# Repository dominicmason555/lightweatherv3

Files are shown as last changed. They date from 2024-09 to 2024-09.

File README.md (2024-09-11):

# Light Weather V3

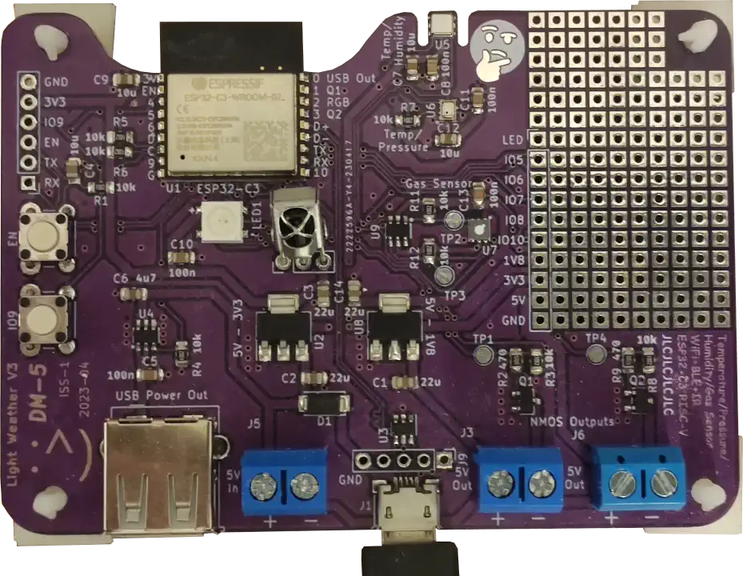
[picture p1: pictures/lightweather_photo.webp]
Photo of assembled project PCB


I made a temperature/pressure/humidity/gas sensor and general I/O interface for
my "smart flat".

[Full write-up](https://domson.dev/projects/lightweather.html) of versions 1
through 3 (this version) on my [personal website](https://domson.dev).

It features an ESP32-C3 controlling two NMOS outputs, one current-limited USB A
(power only) output, and an addressable RGB LED. It has pressure, temperature,
humidity, and gas sensors, and an IR receiver. These can be controlled using
MQTT over WiFi, or using an IR remote.

- [Schematic](./pictures/lightweather_schematic.pdf)
- [Firmware](./firmware/)

The hardware and firmware are open-source, the firmware (everything in
the [firmware](./firmware/) directory) is licensed under the
[GPL V3](./firmware/LICENSE).
The hardware (everything else) is licensed under the
[CERN Open Hardware Licence Version 2 - Strongly Reciprocal](./LICENSE).
The general gist is that if you feel like using or modifying anything here,
good luck, have fun, and publish what you make as open-source too.

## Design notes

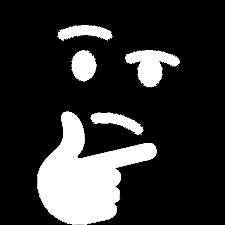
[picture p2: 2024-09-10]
Images/thinkmask.png

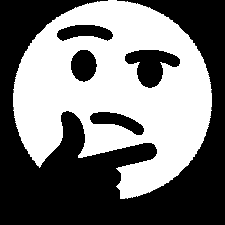
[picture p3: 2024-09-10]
Images/thinksilk.png

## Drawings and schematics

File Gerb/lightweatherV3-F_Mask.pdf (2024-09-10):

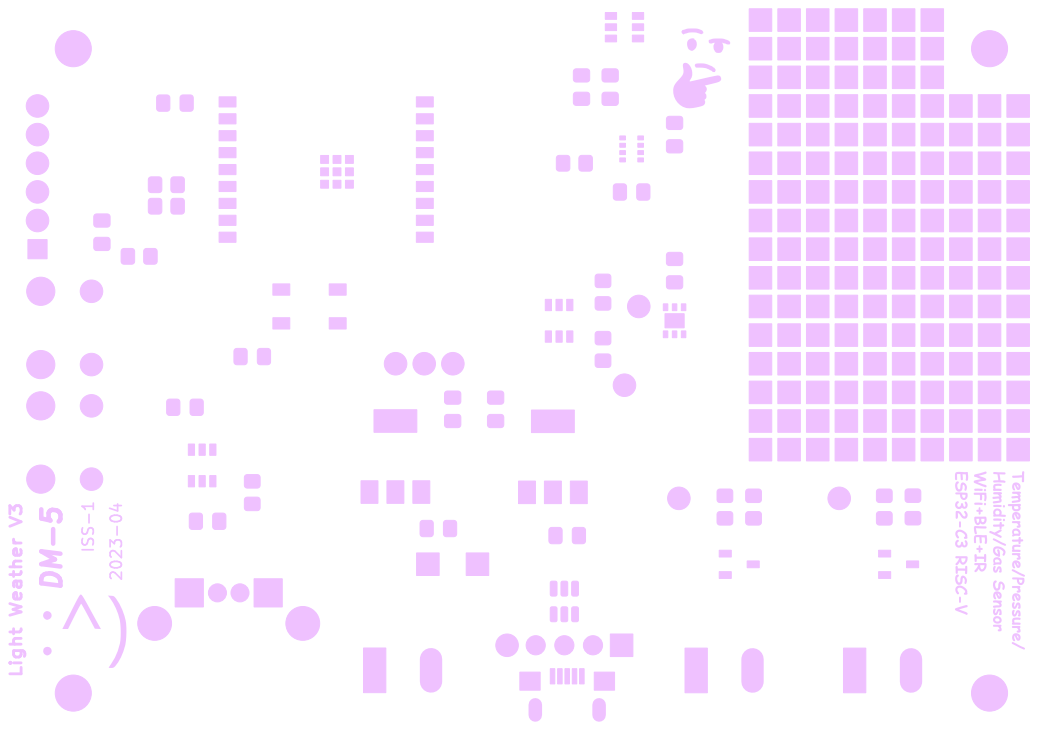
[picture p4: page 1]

ISS-1 2023-04 Humidity/Gas Temperature/Pressure/ Sensor ESP32-C3 WiFi+BLE+IRRISC-VDM-5 Light Weather V3

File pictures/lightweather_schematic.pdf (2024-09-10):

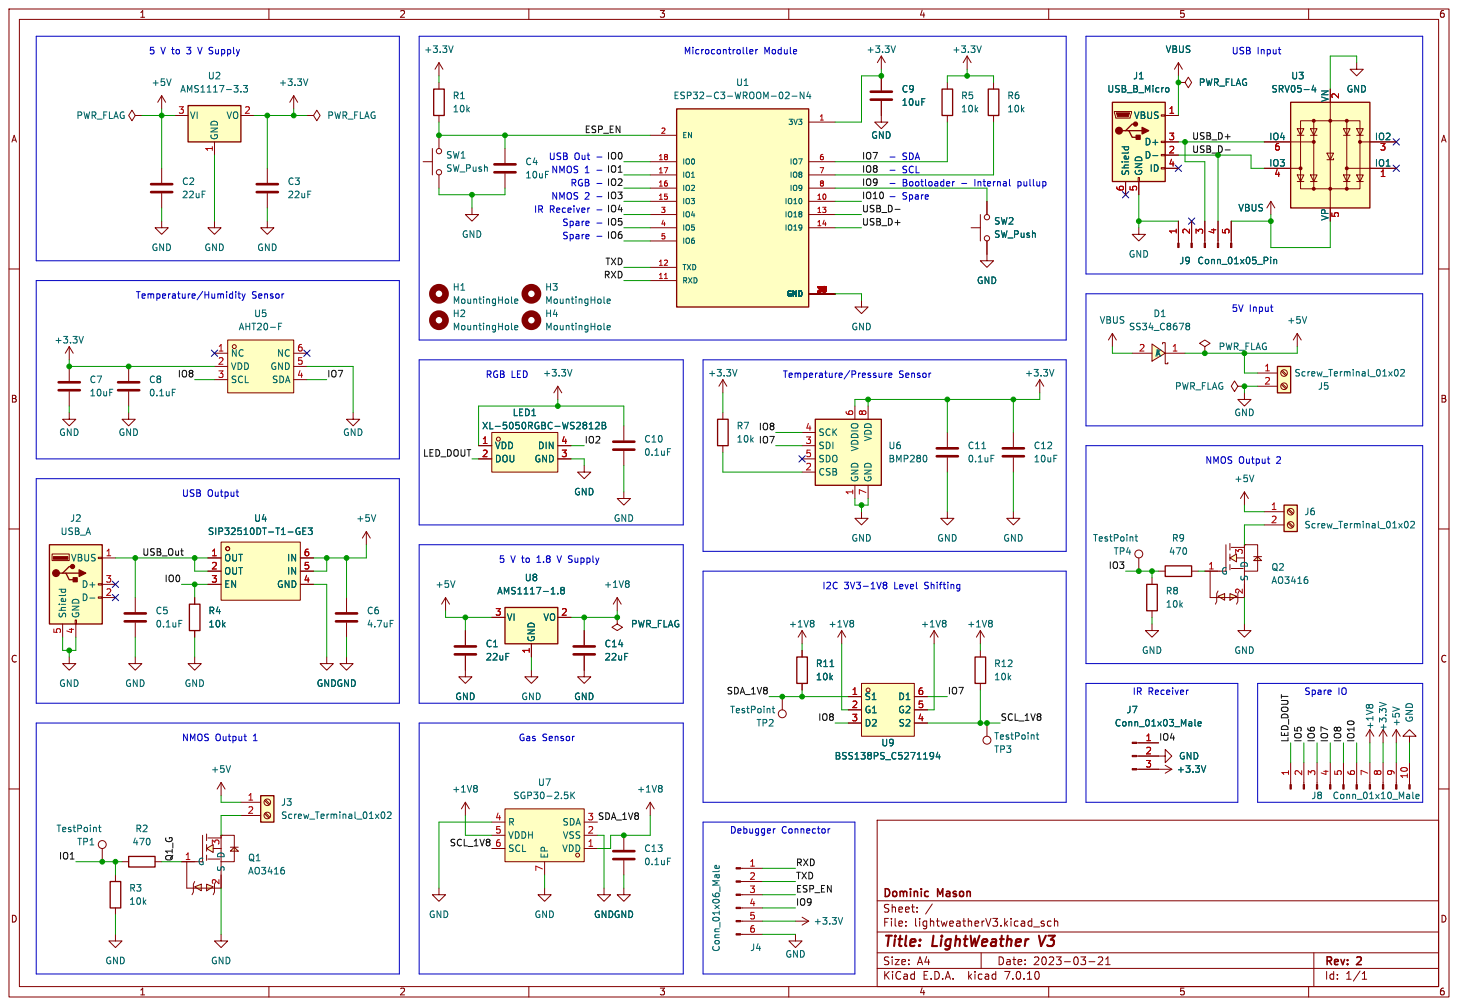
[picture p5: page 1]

1 CSB 2 SDI 3 SCK 4 SDO 5 VDDIO

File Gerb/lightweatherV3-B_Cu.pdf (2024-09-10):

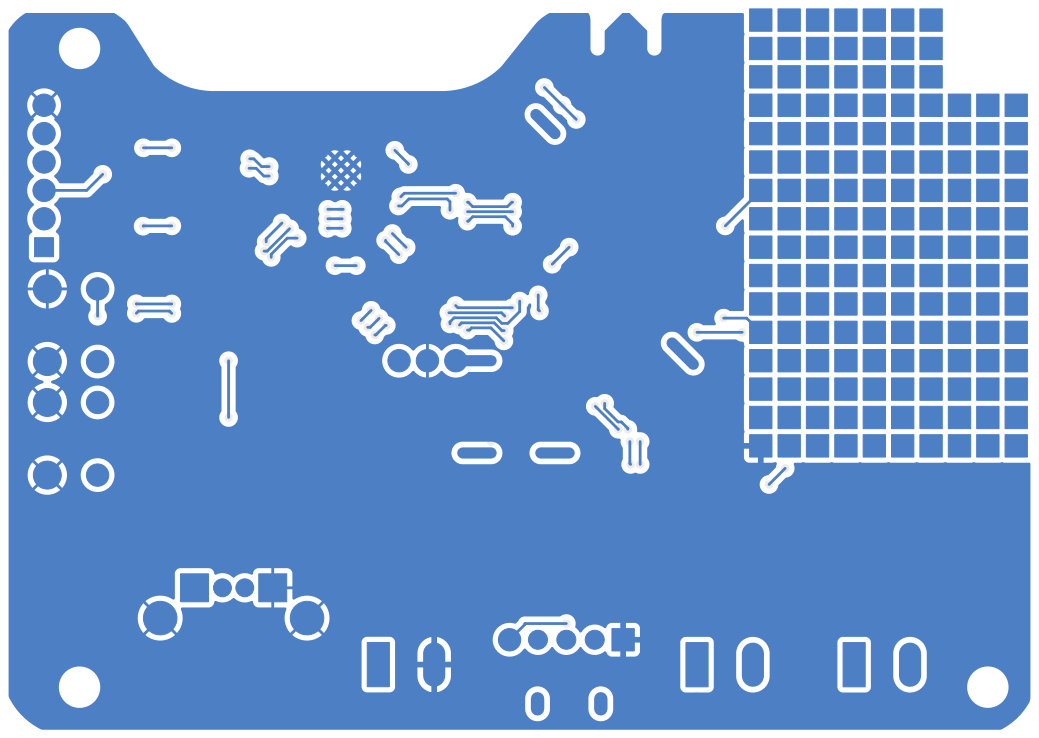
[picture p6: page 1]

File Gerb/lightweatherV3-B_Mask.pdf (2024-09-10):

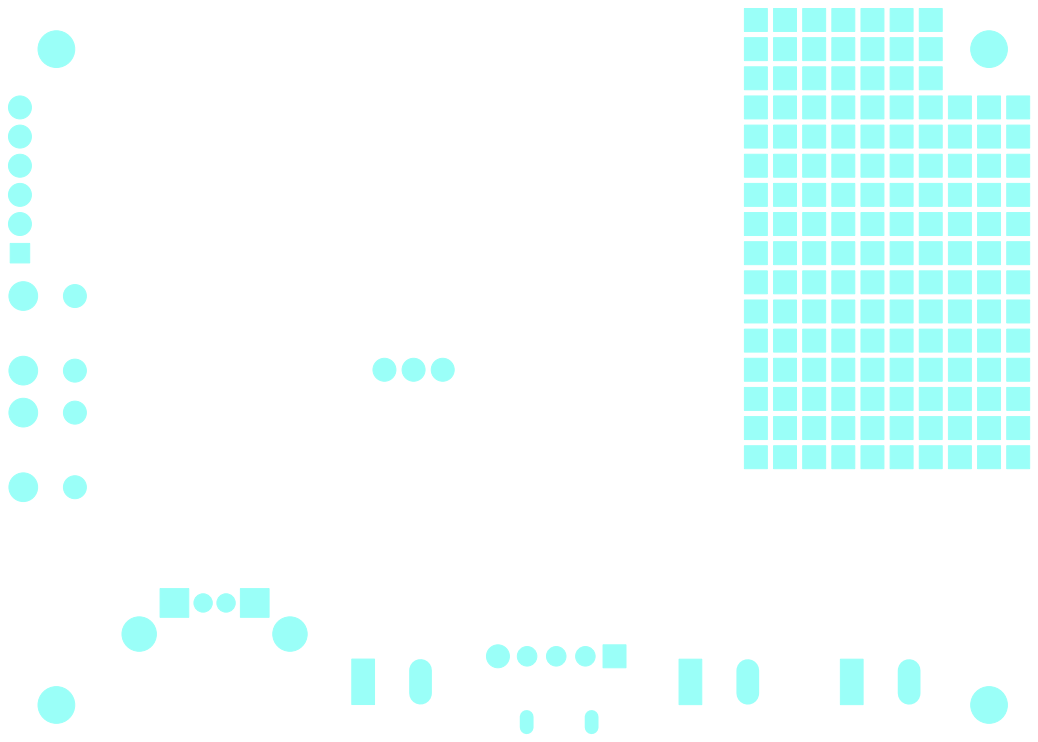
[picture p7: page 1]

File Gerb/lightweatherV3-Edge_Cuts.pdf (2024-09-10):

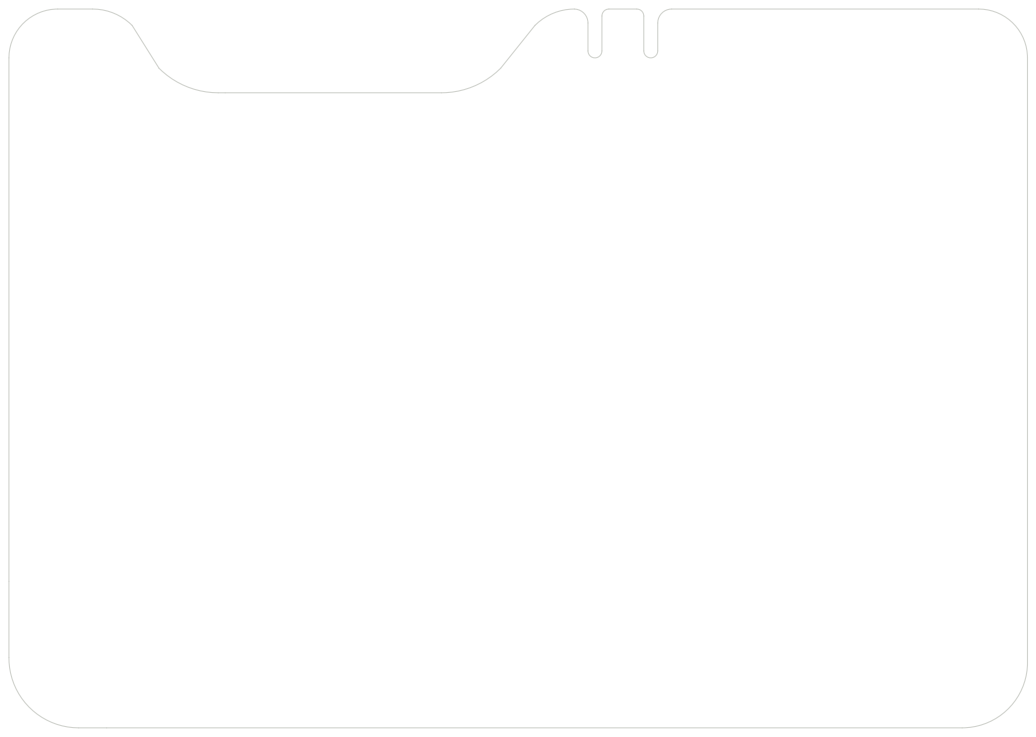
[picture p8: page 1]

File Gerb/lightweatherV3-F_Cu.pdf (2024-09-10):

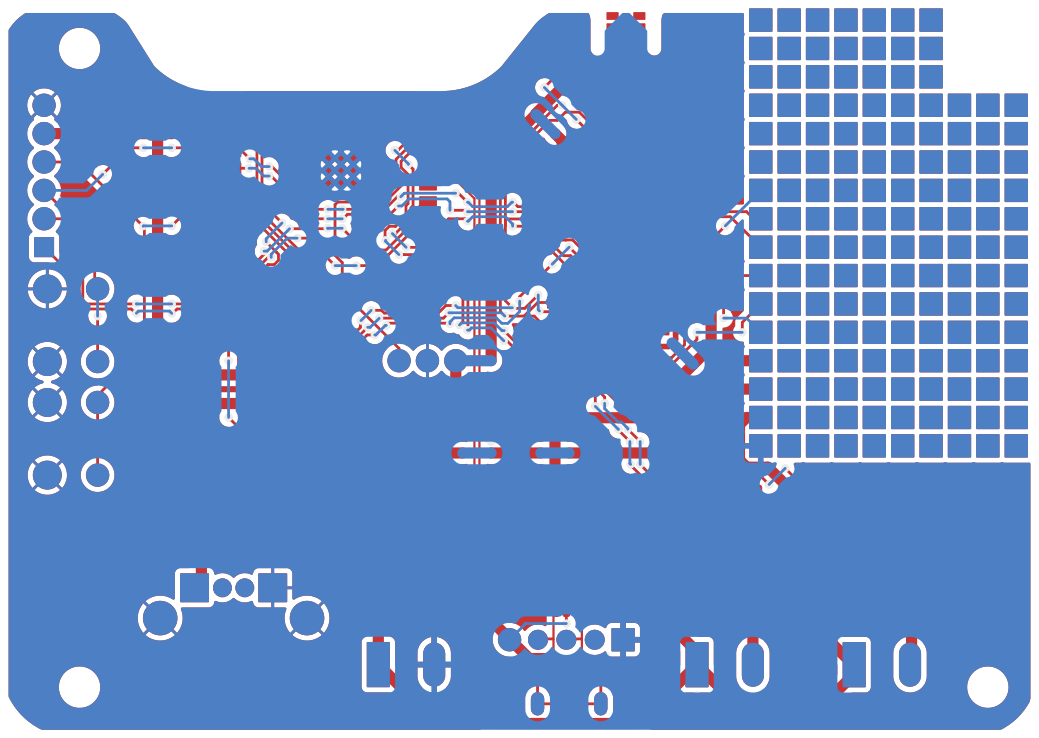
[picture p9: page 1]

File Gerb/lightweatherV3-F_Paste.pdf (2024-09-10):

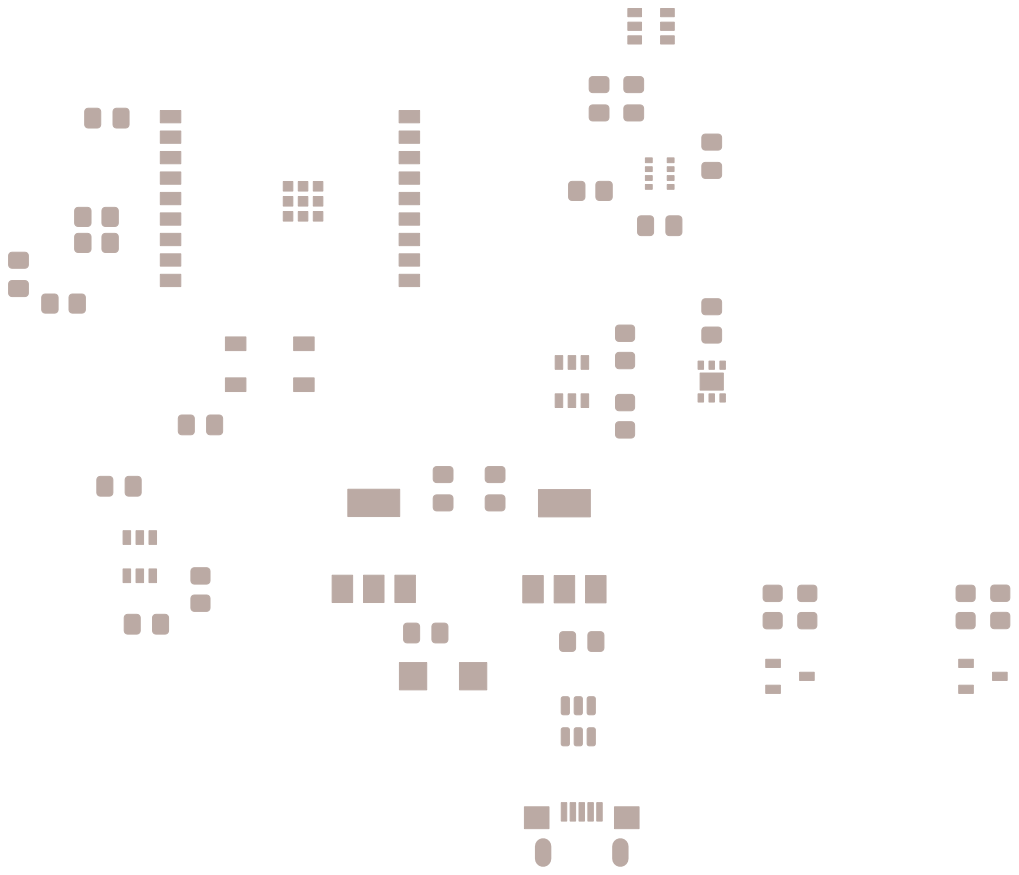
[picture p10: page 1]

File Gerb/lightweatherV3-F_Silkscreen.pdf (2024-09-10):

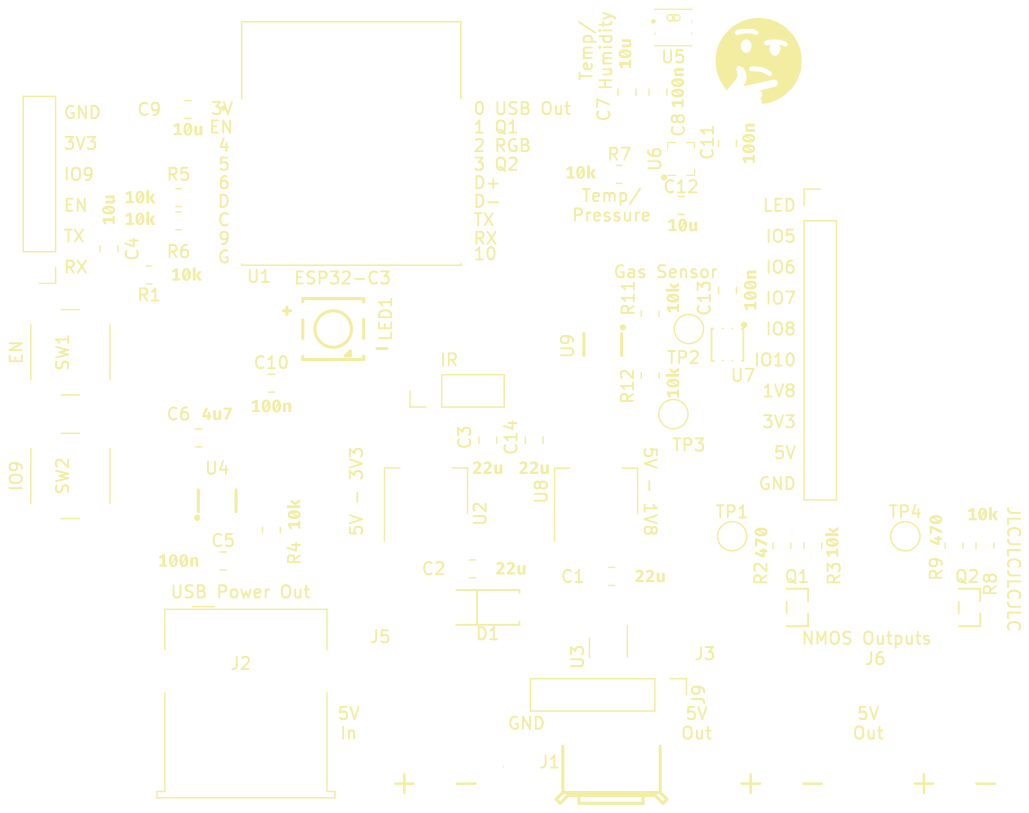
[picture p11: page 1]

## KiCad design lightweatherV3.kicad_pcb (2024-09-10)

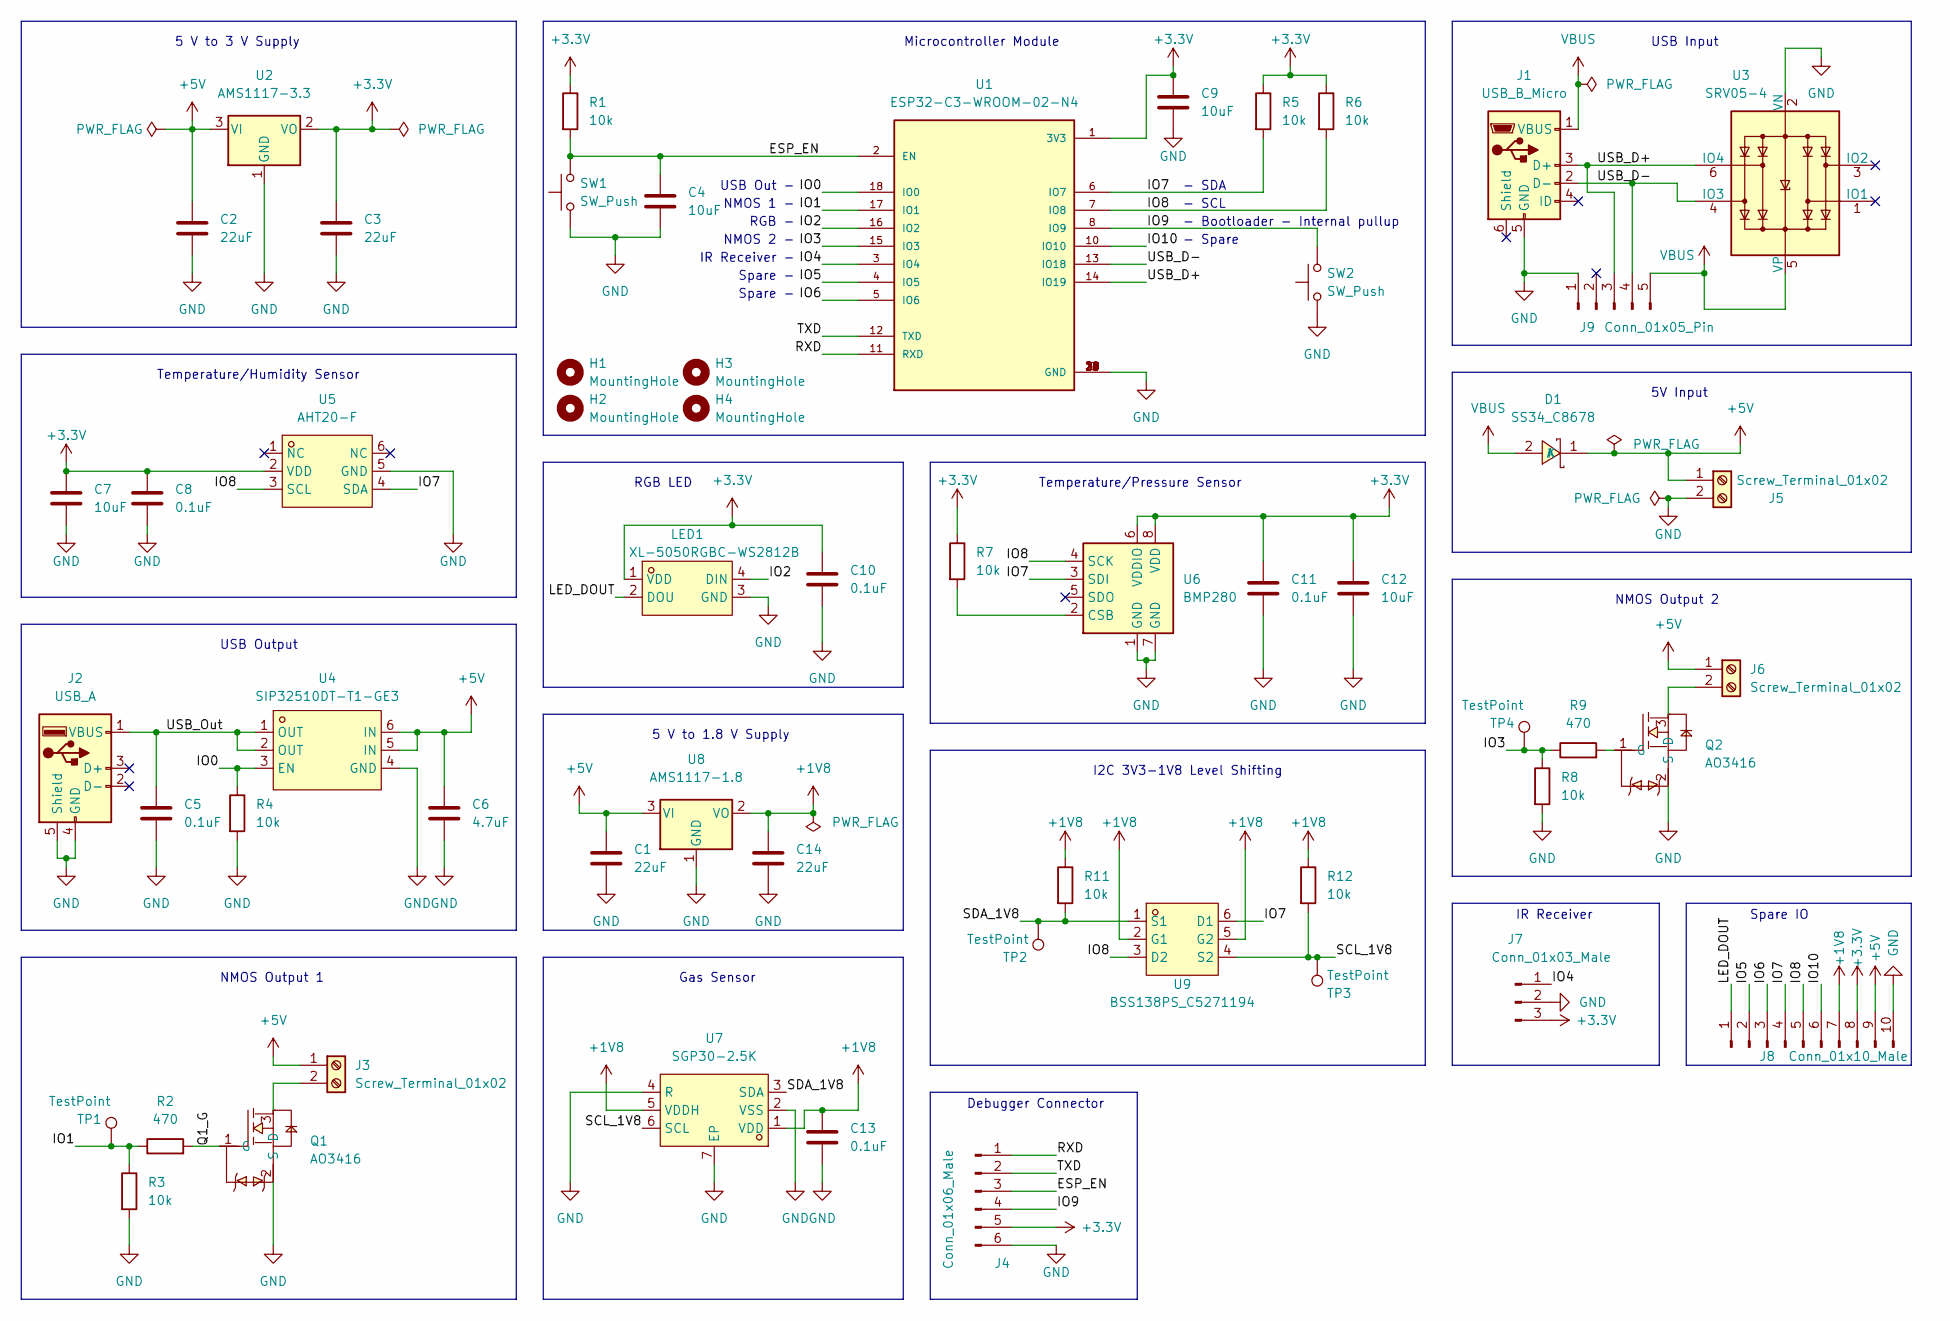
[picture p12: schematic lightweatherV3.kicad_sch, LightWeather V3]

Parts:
C1, C2, C3, C14: 22uF; C_0805_2012Metric_Pad1.18x1.45mm_HandSolder
C4, C7, C9, C12: 10uF; C_0805_2012Metric_Pad1.18x1.45mm_HandSolder
C5, C8, C10, C11, C13: 0.1uF; C_0805_2012Metric_Pad1.18x1.45mm_HandSolder
C6: 4.7uF; C_0805_2012Metric_Pad1.18x1.45mm_HandSolder
D1: SS34_C8678; SMA_L4.3-W2.6-LS5.2-RD; LCSC Part C8678
H1, H2, H3, H4: MountingHole; MountingHole_3.2mm_M3
J1: USB_B_Micro; MICRO-USB-SMD_U254-051T-4BH83-S1S
J2: USB_A; USB_A_Molex_67643_Horizontal
J3, J5, J6: Screw_Terminal_01x02; TerminalBlock_Altech_AK300-2_P5.00mm
J4: Conn_01x06_Male; PinHeader_1x06_P2.54mm_Vertical
J7: Conn_01x03_Male; PinHeader_1x03_P2.54mm_Vertical
J8: Conn_01x10_Male; PinHeader_1x10_P2.54mm_Vertical
J9: Conn_01x05_Pin; PinHeader_1x05_P2.54mm_Vertical
LED1: XL-5050RGBC-WS2812B; LED-SMD_4P-L5.0-W5.0-BL_XL-5050RGBC; LCSC Part C2843785
Q1, Q2: AO3416; SOT-23-3_L2.9-W1.6-P1.90-LS2.8-BR; LCSC Part C43307
R1, R3, R4, R5, R6, R7, R8, R11, R12: 10k; R_0805_2012Metric_Pad1.20x1.40mm_HandSolder
R2, R9: 470; R_0805_2012Metric_Pad1.20x1.40mm_HandSolder
SW1, SW2: SW_Push; SW_PUSH_6mm
TP1, TP2, TP3, TP4: TestPoint; TestPoint_Pad_D2.0mm
U1: ESP32-C3-WROOM-02-N4; MODULE_ESP32-C3-WROOM-02-H4
U2: AMS1117-3.3; SOT-223-3_TabPin2
U3: SRV05-4; SOT-23-6
U4: SIP32510DT-T1-GE3; SOT-23-6_L2.9-W1.6-P0.95-LS2.8-BR; LCSC Part C145264
U5: AHT20-F; SENSOR-SMD-6_AHT20; LCSC Part C3012622
U6: BMP280; Bosch_LGA-8_2x2.5mm_P0.65mm_ClockwisePinNumbering
U7: SGP30-2.5K; DFN-6_L2.5-W2.5-P0.8-BL-EP; LCSC Part C514454
U8: AMS1117-1.8; SOT-223-3_TabPin2
U9: BSS138PS_C5271194; SOT-23-6_L2.9-W1.6-P0.95-LS2.8-BR; LCSC Part C5271194

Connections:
+1V8: C13.1, C14.1, J8.7, R11.1, R12.1, U7.1 (VDD), U7.5 (VDDH), U8.2 (VO), U9.2 (G1), U9.5 (G2)
+3.3V: C3.1, C7.1, C8.1, C9.1, C10.1, C11.1, C12.1, J4.5, J7.3, J8.8, LED1.1 (VDD), R1.1, R5.1, R6.1, R7.1, U1.1 (3V3), U2.2 (VO), U5.2 (VDD), U6.6 (VDDIO), U6.8 (VDD)
+5V: C1.1, C2.1, C6.1, D1.1 (K), J3.1, J5.1, J6.1, J8.9, U2.3 (VI), U4.5 (IN), U4.6 (IN), U8.3 (VI)
/ESP_EN: C4.1, J4.3, R1.2, SW1.2, U1.2 (EN)
/IO0: R4.1, U1.18 (IO0), U4.3 (EN)
/IO1: R2.1, R3.1, TP1.1, U1.17 (IO1)
/IO2: LED1.4 (DIN), U1.16 (IO2)
/IO3: R8.1, R9.1, TP4.1, U1.15 (IO3)
/IO4: J7.1, U1.3 (IO4)
/IO5: J8.2, U1.4 (IO5)
/IO6: J8.3, U1.5 (IO6)
/IO7: J8.4, R5.2, U1.6 (IO7), U5.4 (SDA), U6.3 (SDI), U9.6 (D1)
/IO8: J8.5, R6.2, U1.7 (IO8), U5.3 (SCL), U6.4 (SCK), U9.3 (D2)
/IO9: J4.4, SW2.2, U1.8 (IO9)
/IO10: J8.6, U1.10 (IO10)
/LED_DOUT: J8.1, LED1.2 (DOU)
/Q1_G: Q1.1 (G), R2.2
/RXD: J4.1, U1.11 (RXD)
/SCL_1V8: R12.2, TP3.1, U7.6 (SCL), U9.4 (S2)
/SDA_1V8: R11.2, TP2.1, U7.3 (SDA), U9.1 (S1)
/TXD: J4.2, U1.12 (TXD)
/USB_D+: J1.3 (D+), J9.3, U1.14 (IO19), U3.6 (IO4)
/USB_D-: J1.2 (D-), J9.4, U1.13 (IO18), U3.4 (IO3)
/USB_Out: C5.1, J2.1 (VBUS), U4.1 (OUT), U4.2 (OUT)
GND: C1.2, C2.2, C3.2, C4.2, C5.2, C6.2, C7.2, C8.2, C9.2, C10.2, C11.2, C12.2, C13.2, C14.2, J1.5 (GND), J2.4 (GND), J2.5 (Shield), J4.6, J5.2, J7.2, J8.10, J9.1, LED1.3 (GND), Q1.2 (S), Q2.2 (S), R3.2, R4.2, R8.2, SW1.1, SW2.1, U1.9 (GND), U1.19 (GND), U1.20 (GND), U1.21 (GND), U1.22 (GND), U1.23 (GND), U1.24 (GND), U1.25 (GND), U1.26 (GND), U1.27 (GND), U1.28 (GND), U1.29 (GND), U1.30 (GND), U1.31 (GND), U1.32 (GND), U1.33 (GND), U1.34 (GND), U1.35 (GND), U1.36 (GND), U1.37 (GND), U1.38 (GND), U1.39 (GND), U2.1 (GND), U3.2 (VN), U4.4 (GND), U5.5 (GND), U6.1 (GND), U6.7 (GND), U7.2 (VSS), U7.4 (R), U7.7 (EP), U8.1 (GND)
unnamed: J3.2, Q1.3 (D)
unnamed: J6.2, Q2.3 (D)
unnamed: Q2.1 (G), R9.2
unnamed: R7.2, U6.2 (CSB)
VBUS: D1.2 (A), J1.1 (VBUS), J9.5, U3.5 (VP)

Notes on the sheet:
- Bootloader - Internal pullup
- SDA
Spare IO
5 V to 1.8 V Supply
NMOS Output 1
Debugger Connector
- SCL
NMOS Output 2
5V Input
NMOS 1 -
USB Input
5 V to 3 V Supply
USB Out -
RGB LED
IR Receiver -
Temperature/Humidity Sensor
NMOS 2 -
IR Receiver
I2C 3V3-1V8 Level Shifting
Microcontroller Module
Temperature/Pressure Sensor
Spare -
Gas Sensor
RGB -
- Spare
USB Output

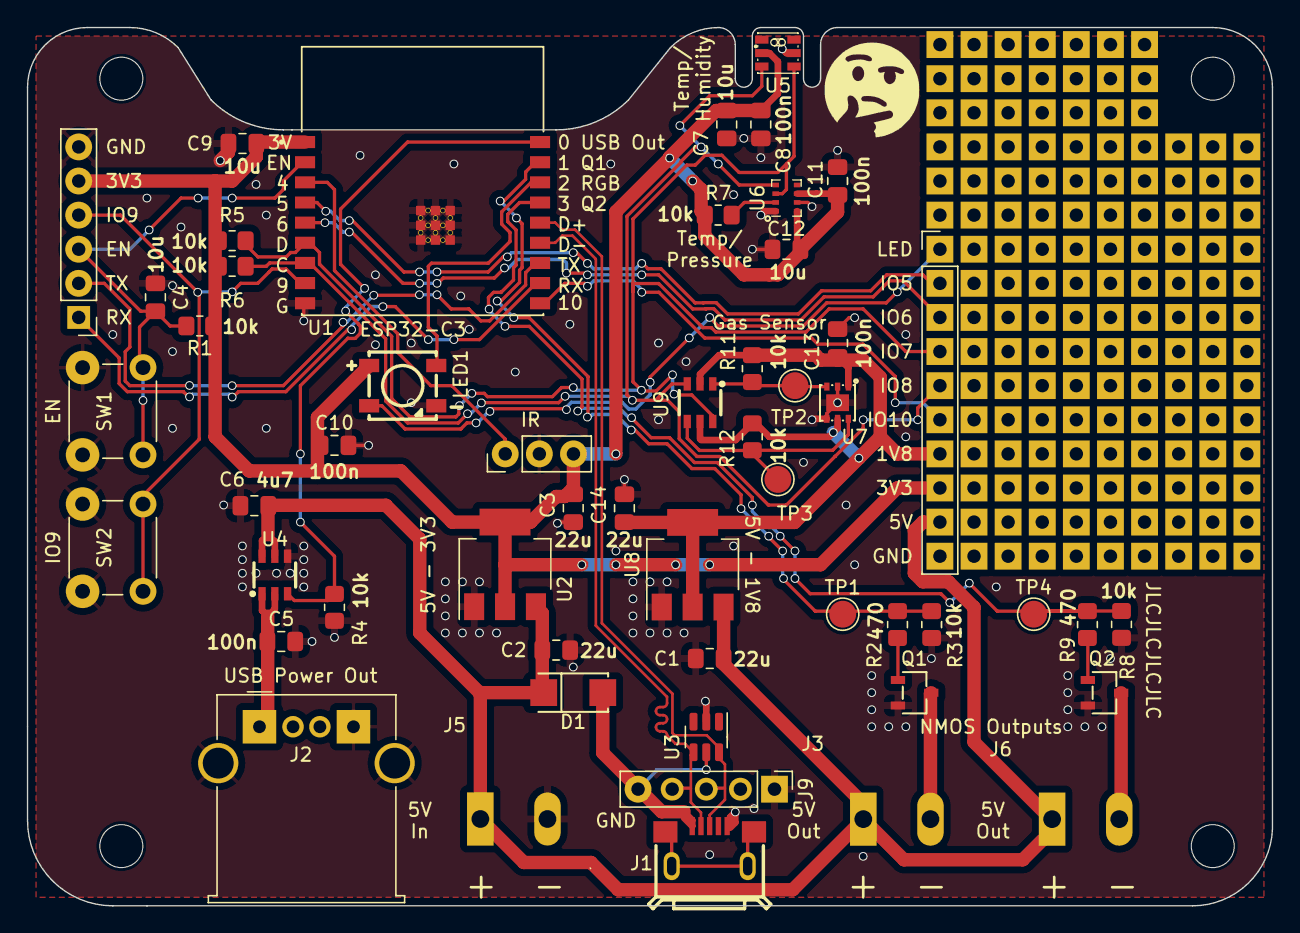
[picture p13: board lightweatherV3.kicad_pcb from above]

Board: 2 copper layers, 92.7 x 65.4 mm, 57 parts (0 on the bottom side), 30 nets.

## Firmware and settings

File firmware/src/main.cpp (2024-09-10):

#include <Arduino.h>

#include <Wire.h>
#include <array>

#include "ESP8266WiFi.h"
#include "AsyncMqttClient.h"
#include "ArduinoJSON.h"
#include "IRremoteESP8266.h"

#include "evq.hpp"
#include "ir.hpp"
#include "io.hpp"
#include "mqtt.hpp"
#include "weather.hpp"
#include "credentials.hpp"


Queues queues;
Ir ir;
Mqtt mqtt;
Io io;
Weather weather;

const uint32_t COUNT_MAX = 120; // One minute until restart
uint32_t restart_countdown = COUNT_MAX;


void check_wifi()
{
    if (WiFi.status() != WL_CONNECTED)
    {
        uint8_t connection_attempts = 0;
        while (WiFi.status() != WL_CONNECTED && connection_attempts < 50)
        {
            delay(500);
            Serial.print(".");
            connection_attempts++;
        }

        if (WiFi.status() == WL_CONNECTED)
        {
            Serial.println("\nConnected to WiFi");
        }
        else
        {
            Serial.println("Failed to connect to WiFi, restarting...");
            ESP.restart();
        }
    }
}


void check_mqtt()
{
    if (mqtt.is_connected())
    {
        restart_countdown = COUNT_MAX;
    }
    else
    {
        restart_countdown--;
        mqtt.connect();
        delay(500);
    }
    if (restart_countdown == 0)
    {
        Serial.println("Failed to reconnect to MQTT, restarting...");
        ESP.restart();
    }
}


void connect_wifi()
{
    Serial.print("Connecting to Wi-Fi");
    WiFi.mode(WIFI_STA);
    WiFi.begin(SSID, WiFi_Pass);
    check_wifi();
    WiFi.setAutoReconnect(true);
    WiFi.persistent(true);
}


void setup()
{
    Wire.begin(2, 14);
    pinMode(13, OUTPUT);
    pinMode(4, OUTPUT);
    Serial.begin(115200);

    connect_wifi();

    ir.setup();
    io.setup();
    weather.setup();
    mqtt.setup(&queues);
}

void loop()
{
    check_wifi();
    check_mqtt();
    ir.loop(queues);
    weather.loop(queues);
    mqtt.loop(queues);
    io.loop(queues);
}
